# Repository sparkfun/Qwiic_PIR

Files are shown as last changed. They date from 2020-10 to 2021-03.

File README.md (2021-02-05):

SparkFun Qwiic PIR - 1&micro;A (EKMB1107112) & 170&micro;A (EKMC4607112K)
========================================

<table class="table table-hover table-striped table-bordered">
    <tr align="center">
      <td></td>
      <td></td>
    </tr>
    <tr align="center">
      <td><a href="https://www.sparkfun.com/products/17375">SparkFun Qwiic PIR - 1&micro;A (EKMB1107112)</a></td>
      <td><a href="https://www.sparkfun.com/products/17374">SparkFun Qwiic PIR - 170&micro;A (EKMC4607112K)</a></td>
    </tr>
</table>

The SparkFun Qwiic PIRs feature low-profile EKM-series PIR sensors from Panasonic for motion sensing projects using I<sup>2</sup>C. The two versions offer motion-sensing options for both battery powered (SparkFun Qwiic PIR - 1&micro;A (EKMB1107112)) and continuously powered (SparkFun Qwiic PIR - 170&micro;A (EKMC4607112K)) applications. The Qwiic PIR features an ATTiny84 to translate the PIR's digital output signal into I<sup>2</sup>C data so it can be integrated into an existing Qwiic or I<sup>2</sup>C bus.

Repository Contents
-------------------

* **/Documentation** - Data sheets, additional product information
* **/Firmware** - Qwiic PIR Firmware
* **/Hardware** - Eagle design files (.brd, .sch)
* **/Production** - Production panel files (.brd)

Documentation
--------------
* **[Qwiic PIR Arduino Library](https://github.com/sparkfun/SparkFun_Qwiic_PIR_Arduino_Library)** - Arduino library for the SparkFun Qwiic PIR.
* **[Qwiic PIR Python Library](https://github.com/sparkfun/Qwiic_PIR_Py)** - Python library for the SparkFun Qwiic PIR.
* **[Hookup Guide](https://learn.sparkfun.com/tutorials/qwiic-pir-hookup-guide)** - Basic hookup guide for the SparkFun Qwiic PIR.
* **[SparkFun Fritzing repo](https://github.com/sparkfun/Fritzing_Parts)** - Fritzing diagrams for SparkFun products.

Product Versions
----------------
* [SEN-17374](https://www.sparkfun.com/products/17374) - 170&micro;A version
* [SEN-17375](https://www.sparkfun.com/products/17375) - 1&micro;A version

Version History
---------------
* [v10](https://www.sparkfun.com/products/17374) - Initial release of SparkFun Qwiic PIR - 170&micro;A

License Information
-------------------

This product is _**open source**_! 

Please review the LICENSE.md file for license information. 

If you have any questions or concerns on licensing, please contact technical support on our [SparkFun forums](https://forum.sparkfun.com/viewforum.php?f=152).

Distributed as-is; no warranty is given.

- Your friends at SparkFun.

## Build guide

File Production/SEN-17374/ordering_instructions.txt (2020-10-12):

panel size, 195x143mm
PCB thickness, 1.6mm
number of layers, 2
soldermask color, Red
silkscreen color, White
oz copper, 1oz
finish, HASL lead free
stencils, top
pcs per panel, 35
min trace width, 0.1778mm / 0.0070in
min drill size, 0.3810mm / 0.0150in

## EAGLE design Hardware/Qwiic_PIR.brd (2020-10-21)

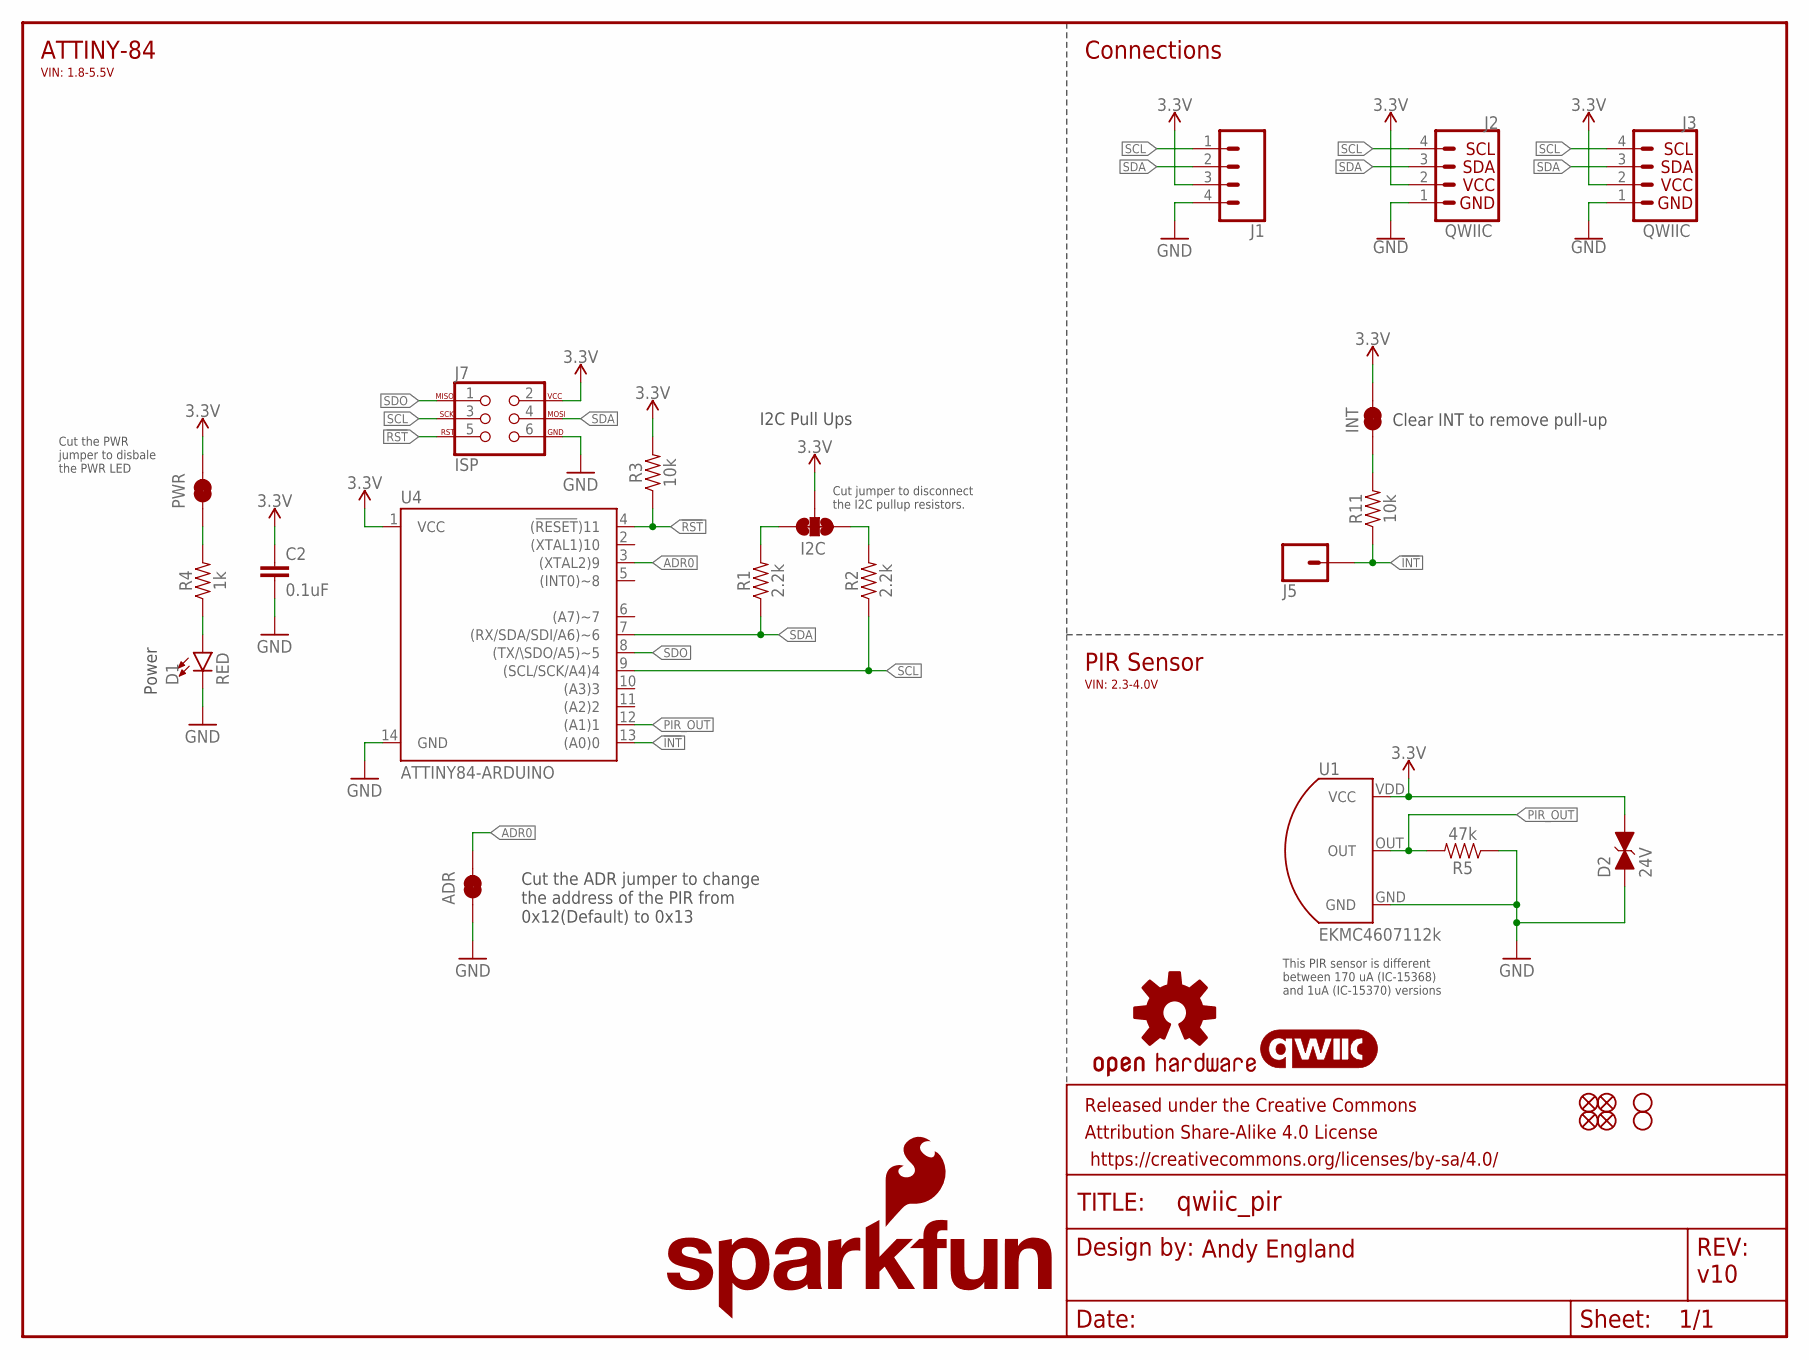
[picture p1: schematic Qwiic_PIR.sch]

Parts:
ADR: JUMPER-SMT_2_NC_TRACE_SILK; SMT-JUMPER_2_NC_TRACE_SILK
C2: 0.1uF; 0603
D1: RED; LED-0603
D2: 24V; 0603
FRAME1: FRAME-LETTER; CREATIVE_COMMONS
H1, H2: STAND-OFF
I2C: JUMPER-SMT_3_2-NC_TRACE_SILK; SMT-JUMPER_3_2-NC_TRACE_SILK
INT: JUMPER-SMT_2_NC_TRACE_SILK; SMT-JUMPER_2_NC_TRACE_SILK
J1: CONN_041X04_NO_SILK; 1X04_NO_SILK
J2, J3: QWIIC; JST04_1MM_RA
J5: CONN_01PTH_NO_SILK_YES_STOP; 1X01_NO_SILK
J7: ISP; 2X3_TEST_POINTS
JP2, JP6, JP8, JP9: FIDUCIALUFIDUCIAL; MICRO-FIDUCIAL
LOGO1: OSHW-LOGOMINI; OSHW-LOGO-MINI
LOGO2: QWIIC_LOGO_5MM; QWIIC_5MM
LOGO3: SFE_LOGO_NAME.1_INCH; SFE_LOGO_NAME_.1
LOGO4: SFE_LOGO_FLAME.1_INCH; SFE_LOGO_FLAME_.1
PWR: JUMPER-SMT_2_NC_TRACE_SILK; SMT-JUMPER_2_NC_TRACE_SILK
R1, R2: 2.2k; 0603
R3, R11: 10k; 0603
R4: 1k; 0603
R5: 47k; 0603
U1: EKMC4607112k; TO-3
U4: ATTINY84-ARDUINO; SO14

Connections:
3.3V: C2.1, D2.2 (C), I2C.2, INT.2, J1.3, J2.2, J3.2, J7.2, PWR.2, R3.2, U1.VDD (VCC), U4.1 (VCC)
!INT: J5.1, R11.1, U4.13 ((A0)0)
!RST: J7.5, R3.1, U4.4 ((!RESET!)11)
ADR0: ADR.2, U4.3 ((XTAL2)9)
GND: ADR.1, C2.2, D1.C, D2.1 (A), J1.4, J2.1, J3.1, J7.6, R5.1, U1.GND, U4.14 (GND)
INT_R: INT.1, R11.2
unnamed: D1.A, R4.1
PIR_OUT: R5.2, U1.OUT, U4.12 ((A1)1)
SCL: J1.1, J2.4, J3.4, J7.3, R2.1, U4.9 ((SCL/SCK/A4)4)
SCL_PU1: I2C.1, R2.2
SDA: J1.2, J2.3, J3.3, J7.4, R1.1, U4.7 ((RX/SDA/SDI/A6)~6)
SDA_PU1: I2C.3, R1.2
SDO: J7.1, U4.8 ((TX/\SDO/A5)~5)
STAT: PWR.1, R4.2

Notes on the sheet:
v10
Connections
Cut jumper to disconnect the I2C pullup resistors.
Cut the ADR jumper to change the address of the PIR from 0x12(Default) to 0x13
I2C Pull Ups
Power
Clear INT to remove pull-up
Andy England
ATTINY-84
PIR Sensor
VIN: 1.8-5.5V
Cut the PWR jumper to disbale the PWR LED
VIN: 2.3-4.0V
This PIR sensor is different between 170 uA (IC-15368) and 1uA (IC-15370) versions

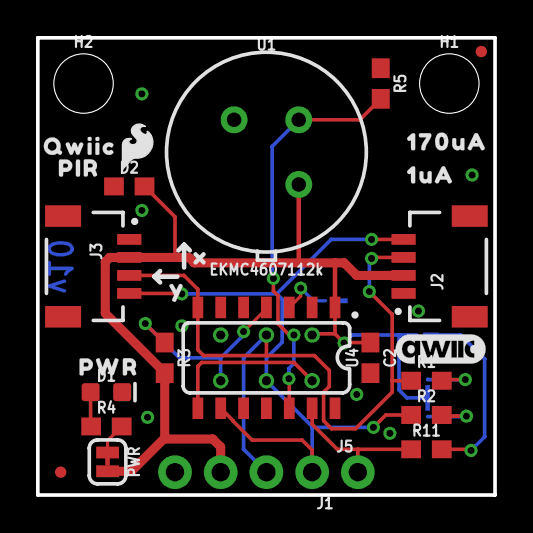
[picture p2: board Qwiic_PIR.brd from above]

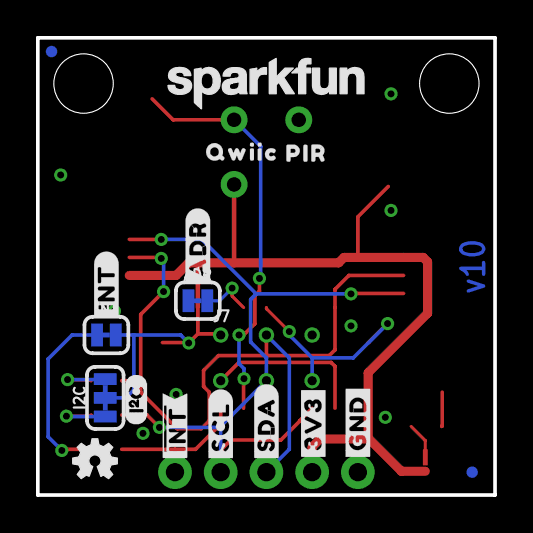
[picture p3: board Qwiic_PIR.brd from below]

Board: 2 copper layers, 25.4 x 25.4 mm, 48 parts (18 on the bottom side), 14 nets.

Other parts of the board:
U$1, U$13: PIR0
U$2: 170UA0
U$3: PWR0
U$4: #INT#0
U$5: #3V3#0
U$6: #SDA#0
U$7: #SCL#0
U$8: ##INT##0
U$9: 1UA0
U$10: I_SUPER2_C-()-03
U$11: #ADR#0
U$14: X0
U$16: Y0
U$17, U$18: QWIIC0
U$19: #GND#0

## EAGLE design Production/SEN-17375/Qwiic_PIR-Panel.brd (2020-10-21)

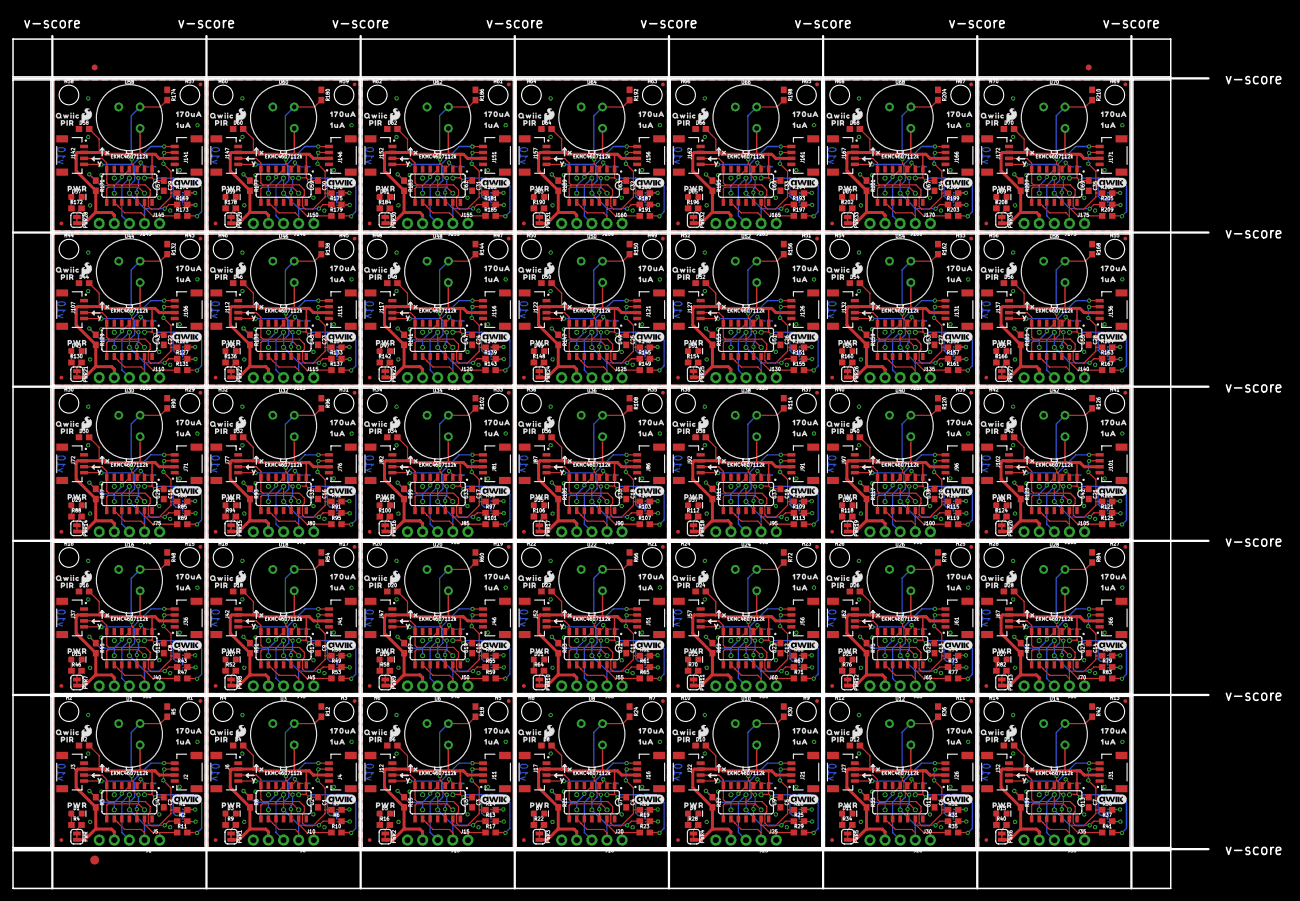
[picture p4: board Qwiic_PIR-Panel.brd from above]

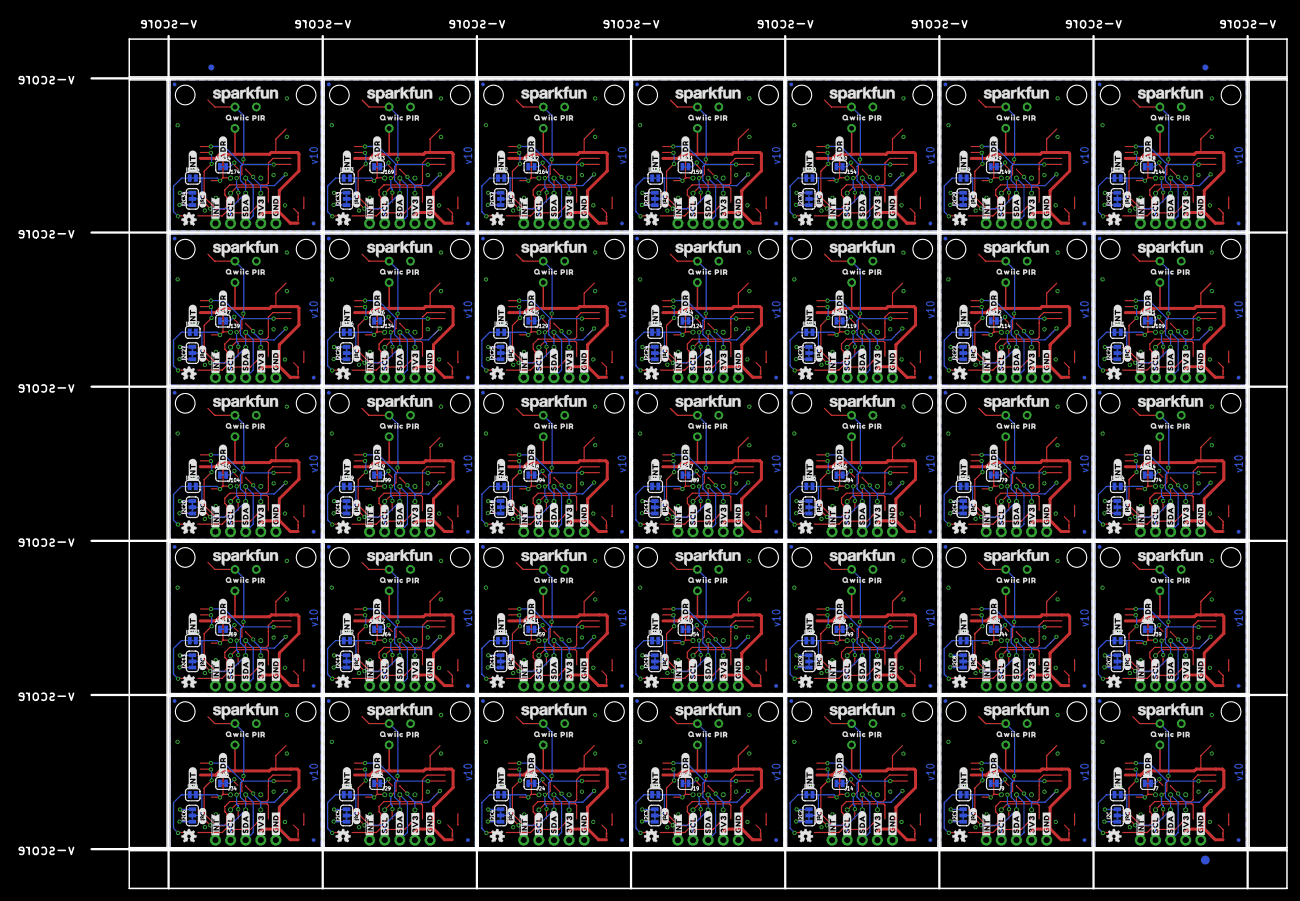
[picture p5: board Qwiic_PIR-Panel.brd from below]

Board: 2 copper layers, 200.9 x 143.3 mm, 1651 parts (633 on the bottom side), 490 nets.

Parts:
ADR, ADR1, ADR2, ADR3, ADR4, ADR5, ADR6, ADR7, ADR8, ADR9, ADR10, ADR11, ADR12, ADR13, ADR14, ADR15, ADR16, ADR17, ADR18, ADR19, ADR20, ADR21, ADR22, ADR23, ADR24, ADR25, ADR26, ADR27, ADR28, ADR29, ADR30, ADR31, ADR32, ADR33, ADR34: JUMPER-SMT_2_NC_TRACE_SILK; SMT-JUMPER_2_NC_TRACE_SILK
C1, C2, C3, C4, C5, C6, C7, C8, C9, C10, C11, C12, C13, C14, C15, C16, C17, C18, C19, C20, C21, C22, C23, C24, C25, C26, C27, C28, C29, C30, C31, C32, C33, C34, C35: 0.1uF; 0603
D1, D3, D5, D7, D9, D11, D13, D15, D17, D19, D21, D23, D25, D27, D29, D31, D33, D35, D37, D39, D41, D43, D45, D47, D49, D51, D53, D55, D57, D59, D61, D63, D65, D67, D69: RED; LED-0603
D2, D4, D6, D8, D10, D12, D14, D16, D18, D20, D22, D24, D26, D28, D30, D32, D34, D36, D38, D40, D42, D44, D46, D48, D50, D52, D54, D56, D58, D60, D62, D64, D66, D68, D70: 24V; 0603
E$1, E$2, E$3, E$4: FIDUCIAL-1X2
E$5, E$6: FIDUCIAL-1.5X3
H1, H2, H3, H4, H5, H6, H7, H8, H9, H10, H11, H12, H13, H14, H15, H16, H17, H18, H19, H20, H21, H22, H23, H24, H25, H26, H27, H28, H29, H30, H31, H32, H33, H34, H35, H36, H37, H38, H39, H40, H41, H42, H43, H44, H45, H46, H47, H48, H49, H50, H51, H52, H53, H54, H55, H56, H57, H58, H59, H60, H61, H62, H63, H64, H65, H66, H67, H68, H69, H70: STAND-OFF
I2C, I2C1, I2C2, I2C3, I2C4, I2C5, I2C6, I2C7, I2C8, I2C9, I2C10, I2C11, I2C12, I2C13, I2C14, I2C15, I2C16, I2C17, I2C18, I2C19, I2C20, I2C21, I2C22, I2C23, I2C24, I2C25, I2C26, I2C27, I2C28, I2C29, I2C30, I2C31, I2C32, I2C33, I2C34: JUMPER-SMT_3_2-NC_TRACE_SILK; SMT-JUMPER_3_2-NC_TRACE_SILK
INT, INT1, INT2, INT3, INT4, INT5, INT6, INT7, INT8, INT9, INT10, INT11, INT12, INT13, INT14, INT15, INT16, INT17, INT18, INT19, INT20, INT21, INT22, INT23, INT24, INT25, INT26, INT27, INT28, INT29, INT30, INT31, INT32, INT33, INT34: JUMPER-SMT_2_NC_TRACE_SILK; SMT-JUMPER_2_NC_TRACE_SILK
J1, J8, J13, J18, J23, J28, J33, J38, J43, J48, J53, J58, J63, J68, J73, J78, J83, J88, J93, J98, J103, J108, J113, J118, J123, J128, J133, J138, J143, J148, J153, J158, J163, J168, J173: 1X04_NO_SILK
J2, J3, J4, J6, J11, J12, J16, J17, J21, J22, J26, J27, J31, J32, J36, J37, J41, J42, J46, J47, J51, J52, J56, J57, J61, J62, J66, J67, J71, J72, J76, J77, J81, J82, J86, J87, J91, J92, J96, J97, J101, J102, J106, J107, J111, J112, J116, J117, J121, J122, J126, J127, J131, J132, J136, J137, J141, J142, J146, J147, J151, J152, J156, J157, J161, J162, J166, J167, J171, J172: QWIIC; JST04_1MM_RA
J5, J10, J15, J20, J25, J30, J35, J40, J45, J50, J55, J60, J65, J70, J75, J80, J85, J90, J95, J100, J105, J110, J115, J120, J125, J130, J135, J140, J145, J150, J155, J160, J165, J170, J175: 1X01_NO_SILK
J7, J9, J14, J19, J24, J29, J34, J39, J44, J49, J54, J59, J64, J69, J74, J79, J84, J89, J94, J99, J104, J109, J114, J119, J124, J129, J134, J139, J144, J149, J154, J159, J164, J169, J174: ISP; 2X3_TEST_POINTS
JP1, JP2, JP3, JP4, JP5, JP6, JP7, JP8, JP9, JP10, JP11, JP12, JP13, JP14, JP15, JP16, JP17, JP18, JP19, JP20, JP21, JP22, JP23, JP24, JP25, JP26, JP27, JP28, JP29, JP30, JP31, JP32, JP33, JP34, JP35, JP36, JP37, JP38, JP39, JP40, JP41, JP42, JP43, JP44, JP45, JP46, JP47, JP48, JP49, JP50, JP51, JP52, JP53, JP54, JP55, JP56, JP57, JP58, JP59, JP60, JP61, JP62, JP63, JP64, JP65, JP66, JP67, JP68, JP69, JP70, JP71, JP72, JP73, JP74, JP75, JP76, JP77, JP78, JP79, JP80, JP81, JP82, JP83, JP84, JP85, JP86, JP87, JP88, JP89, JP90, JP91, JP92, JP93, JP94, JP95, JP96, JP97, JP98, JP99, JP100, JP101, JP102, JP103, JP104, JP105, JP106, JP107, JP108, JP109, JP110, JP111, JP112, JP113, JP114, JP115, JP116, JP117, JP118, JP119, JP120, JP121, JP122, JP123, JP124, JP125, JP126, JP127, JP128, JP129, JP130, JP131, JP132, JP133, JP134, JP135, JP136, JP137, JP138, JP139, JP140: FIDUCIALUFIDUCIAL; MICRO-FIDUCIAL
LOGO1, LOGO5, LOGO9, LOGO13, LOGO17, LOGO21, LOGO25, LOGO29, LOGO33, LOGO37, LOGO41, LOGO45, LOGO49, LOGO53, LOGO57, LOGO61, LOGO65, LOGO69, LOGO73, LOGO77, LOGO81, LOGO85, LOGO89, LOGO93, LOGO97, LOGO101, LOGO105, LOGO109, LOGO113, LOGO117, LOGO121, LOGO125, LOGO129, LOGO133, LOGO137: OSHW-LOGOMINI; OSHW-LOGO-MINI
LOGO2, LOGO8, LOGO12, LOGO16, LOGO20, LOGO24, LOGO28, LOGO32, LOGO36, LOGO40, LOGO44, LOGO48, LOGO52, LOGO56, LOGO60, LOGO64, LOGO68, LOGO72, LOGO76, LOGO80, LOGO84, LOGO88, LOGO92, LOGO96, LOGO100, LOGO104, LOGO108, LOGO112, LOGO116, LOGO120, LOGO124, LOGO128, LOGO132, LOGO136, LOGO140: QWIIC_LOGO_5MM; QWIIC_5MM
LOGO3, LOGO6, LOGO10, LOGO14, LOGO18, LOGO22, LOGO26, LOGO30, LOGO34, LOGO38, LOGO42, LOGO46, LOGO50, LOGO54, LOGO58, LOGO62, LOGO66, LOGO70, LOGO74, LOGO78, LOGO82, LOGO86, LOGO90, LOGO94, LOGO98, LOGO102, LOGO106, LOGO110, LOGO114, LOGO118, LOGO122, LOGO126, LOGO130, LOGO134, LOGO138: SFE_LOGO_NAME.1_INCH; SFE_LOGO_NAME_.1
LOGO4, LOGO7, LOGO11, LOGO15, LOGO19, LOGO23, LOGO27, LOGO31, LOGO35, LOGO39, LOGO43, LOGO47, LOGO51, LOGO55, LOGO59, LOGO63, LOGO67, LOGO71, LOGO75, LOGO79, LOGO83, LOGO87, LOGO91, LOGO95, LOGO99, LOGO103, LOGO107, LOGO111, LOGO115, LOGO119, LOGO123, LOGO127, LOGO131, LOGO135, LOGO139: SFE_LOGO_FLAME.1_INCH; SFE_LOGO_FLAME_.1
PWR, PWR1, PWR2, PWR3, PWR4, PWR5, PWR6, PWR7, PWR8, PWR9, PWR10, PWR11, PWR12, PWR13, PWR14, PWR15, PWR16, PWR17, PWR18, PWR19, PWR20, PWR21, PWR22, PWR23, PWR24, PWR25, PWR26, PWR27, PWR28, PWR29, PWR30, PWR31, PWR32, PWR33, PWR34: JUMPER-SMT_2_NC_TRACE_SILK; SMT-JUMPER_2_NC_TRACE_SILK
R1, R2, R6, R7, R13, R14, R19, R20, R25, R26, R31, R32, R37, R38, R43, R44, R49, R50, R55, R56, R61, R62, R67, R68, R73, R74, R79, R80, R85, R86, R91, R92, R97, R98, R103, R104, R109, R110, R115, R116, R121, R122, R127, R128, R133, R134, R139, R140, R145, R146, R151, R152, R157, R158, R163, R164, R169, R170, R175, R176, R181, R182, R187, R188, R193, R194, R199, R200, R205, R206: 2.2k; 0603
R3, R8, R10, R11, R15, R17, R21, R23, R27, R29, R33, R35, R39, R41, R45, R47, R51, R53, R57, R59, R63, R65, R69, R71, R75, R77, R81, R83, R87, R89, R93, R95, R99, R101, R105, R107, R111, R113, R117, R119, R123, R125, R129, R131, R135, R137, R141, R143, R147, R149, R153, R155, R159, R161, R165, R167, R171, R173, R177, R179, R183, R185, R189, R191, R195, R197, R201, R203, R207, R209: 10k; 0603
R4, R9, R16, R22, R28, R34, R40, R46, R52, R58, R64, R70, R76, R82, R88, R94, R100, R106, R112, R118, R124, R130, R136, R142, R148, R154, R160, R166, R172, R178, R184, R190, R196, R202, R208: 1k; 0603
R5, R12, R18, R24, R30, R36, R42, R48, R54, R60, R66, R72, R78, R84, R90, R96, R102, R108, R114, R120, R126, R132, R138, R144, R150, R156, R162, R168, R174, R180, R186, R192, R198, R204, R210: 47k; 0603
U1, U3, U6, U8, U10, U12, U14, U16, U18, U20, U22, U24, U26, U28, U30, U32, U34, U36, U38, U40, U42, U44, U46, U48, U50, U52, U54, U56, U58, U60, U62, U64, U66, U68, U70: EKMC4607112k; TO-3
U2, U4, U5, U7, U9, U11, U13, U15, U17, U19, U21, U23, U25, U27, U29, U31, U33, U35, U37, U39, U41, U43, U45, U47, U49, U51, U53, U55, U57, U59, U61, U63, U65, U67, U69: ATTINY84-ARDUINO; SO14
U$1, U$13, U$15, U$23, U$36, U$40, U$53, U$57, U$70, U$74, U$87, U$91, U$104, U$108, U$121, U$125, U$138, U$142, U$155, U$159, U$172, U$176, U$189, U$193, U$206, U$210, U$223, U$227, U$240, U$244, U$257, U$261, U$274, U$278, U$291, U$295, U$308, U$312, U$325, U$329, U$342, U$346, U$359, U$363, U$376, U$380, U$393, U$397, U$410, U$414, U$427, U$431, U$444, U$448, U$461, U$465, U$478, U$482, U$495, U$499, U$512, U$516, U$529, U$533, U$546, U$550, U$563, U$567, U$580, U$584: PIR0
U$2, U$24, U$41, U$58, U$75, U$92, U$109, U$126, U$143, U$160, U$177, U$194, U$211, U$228, U$245, U$262, U$279, U$296, U$313, U$330, U$347, U$364, U$381, U$398, U$415, U$432, U$449, U$466, U$483, U$500, U$517, U$534, U$551, U$568, U$585: 170UA0
U$3, U$20, U$37, U$54, U$71, U$88, U$105, U$122, U$139, U$156, U$173, U$190, U$207, U$224, U$241, U$258, U$275, U$292, U$309, U$326, U$343, U$360, U$377, U$394, U$411, U$428, U$445, U$462, U$479, U$496, U$513, U$530, U$547, U$564, U$581: PWR0
U$4, U$21, U$38, U$55, U$72, U$89, U$106, U$123, U$140, U$157, U$174, U$191, U$208, U$225, U$242, U$259, U$276, U$293, U$310, U$327, U$344, U$361, U$378, U$395, U$412, U$429, U$446, U$463, U$480, U$497, U$514, U$531, U$548, U$565, U$582: #INT#0
U$5, U$31, U$48, U$65, U$82, U$99, U$116, U$133, U$150, U$167, U$184, U$201, U$218, U$235, U$252, U$269, U$286, U$303, U$320, U$337, U$354, U$371, U$388, U$405, U$422, U$439, U$456, U$473, U$490, U$507, U$524, U$541, U$558, U$575, U$592: #3V3#0
U$6, U$32, U$49, U$66, U$83, U$100, U$117, U$134, U$151, U$168, U$185, U$202, U$219, U$236, U$253, U$270, U$287, U$304, U$321, U$338, U$355, U$372, U$389, U$406, U$423, U$440, U$457, U$474, U$491, U$508, U$525, U$542, U$559, U$576, U$593: #SDA#0
U$7, U$33, U$50, U$67, U$84, U$101, U$118, U$135, U$152, U$169, U$186, U$203, U$220, U$237, U$254, U$271, U$288, U$305, U$322, U$339, U$356, U$373, U$390, U$407, U$424, U$441, U$458, U$475, U$492, U$509, U$526, U$543, U$560, U$577, U$594: #SCL#0
U$8, U$34, U$51, U$68, U$85, U$102, U$119, U$136, U$153, U$170, U$187, U$204, U$221, U$238, U$255, U$272, U$289, U$306, U$323, U$340, U$357, U$374, U$391, U$408, U$425, U$442, U$459, U$476, U$493, U$510, U$527, U$544, U$561, U$578, U$595: ##INT##0
U$9, U$25, U$42, U$59, U$76, U$93, U$110, U$127, U$144, U$161, U$178, U$195, U$212, U$229, U$246, U$263, U$280, U$297, U$314, U$331, U$348, U$365, U$382, U$399, U$416, U$433, U$450, U$467, U$484, U$501, U$518, U$535, U$552, U$569, U$586: 1UA0
U$10, U$12, U$35, U$52, U$69, U$86, U$103, U$120, U$137, U$154, U$171, U$188, U$205, U$222, U$239, U$256, U$273, U$290, U$307, U$324, U$341, U$358, U$375, U$392, U$409, U$426, U$443, U$460, U$477, U$494, U$511, U$528, U$545, U$562, U$579: I_SUPER2_C-()-03
U$11, U$22, U$39, U$56, U$73, U$90, U$107, U$124, U$141, U$158, U$175, U$192, U$209, U$226, U$243, U$260, U$277, U$294, U$311, U$328, U$345, U$362, U$379, U$396, U$413, U$430, U$447, U$464, U$481, U$498, U$515, U$532, U$549, U$566, U$583: #ADR#0
U$14, U$26, U$43, U$60, U$77, U$94, U$111, U$128, U$145, U$162, U$179, U$196, U$213, U$230, U$247, U$264, U$281, U$298, U$315, U$332, U$349, U$366, U$383, U$400, U$417, U$434, U$451, U$468, U$485, U$502, U$519, U$536, U$553, U$570, U$587: X0
U$16, U$27, U$44, U$61, U$78, U$95, U$112, U$129, U$146, U$163, U$180, U$197, U$214, U$231, U$248, U$265, U$282, U$299, U$316, U$333, U$350, U$367, U$384, U$401, U$418, U$435, U$452, U$469, U$486, U$503, U$520, U$537, U$554, U$571, U$588: Y0
U$17, U$18, U$28, U$29, U$45, U$46, U$62, U$63, U$79, U$80, U$96, U$97, U$113, U$114, U$130, U$131, U$147, U$148, U$164, U$165, U$181, U$182, U$198, U$199, U$215, U$216, U$232, U$233, U$249, U$250, U$266, U$267, U$283, U$284, U$300, U$301, U$317, U$318, U$334, U$335, U$351, U$352, U$368, U$369, U$385, U$386, U$402, U$403, U$419, U$420, U$436, U$437, U$453, U$454, U$470, U$471, U$487, U$488, U$504, U$505, U$521, U$522, U$538, U$539, U$555, U$556, U$572, U$573, U$589, U$590: QWIIC0
U$19, U$30, U$47, U$64, U$81, U$98, U$115, U$132, U$149, U$166, U$183, U$200, U$217, U$234, U$251, U$268, U$285, U$302, U$319, U$336, U$353, U$370, U$387, U$404, U$421, U$438, U$455, U$472, U$489, U$506, U$523, U$540, U$557, U$574, U$591: #GND#0

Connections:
3.3V: C2.1, D2.2, I2C.2, INT.2, J1.3, J2.2, J3.2, J7.2, PWR.2, R3.2, U1.VDD, U4.1
3.3V1: C1.1, D4.2, I2C1.2, INT1.2, J4.2, J6.2, J8.3, J9.2, PWR1.2, R8.2, U2.1, U3.VDD
3.3V2: C3.1, D6.2, I2C2.2, INT2.2, J11.2, J12.2, J13.3, J14.2, PWR2.2, R15.2, U5.1, U6.VDD
3.3V3: C4.1, D8.2, I2C3.2, INT3.2, J16.2, J17.2, J18.3, J19.2, PWR3.2, R21.2, U7.1, U8.VDD
3.3V4: C5.1, D10.2, I2C4.2, INT4.2, J21.2, J22.2, J23.3, J24.2, PWR4.2, R27.2, U9.1, U10.VDD
3.3V5: C6.1, D12.2, I2C5.2, INT5.2, J26.2, J27.2, J28.3, J29.2, PWR5.2, R33.2, U11.1, U12.VDD
3.3V6: C7.1, D14.2, I2C6.2, INT6.2, J31.2, J32.2, J33.3, J34.2, PWR6.2, R39.2, U13.1, U14.VDD
3.3V7: C8.1, D16.2, I2C7.2, INT7.2, J36.2, J37.2, J38.3, J39.2, PWR7.2, R45.2, U15.1, U16.VDD
3.3V8: C9.1, D18.2, I2C8.2, INT8.2, J41.2, J42.2, J43.3, J44.2, PWR8.2, R51.2, U17.1, U18.VDD
3.3V9: C10.1, D20.2, I2C9.2, INT9.2, J46.2, J47.2, J48.3, J49.2, PWR9.2, R57.2, U19.1, U20.VDD
3.3V10: C11.1, D22.2, I2C10.2, INT10.2, J51.2, J52.2, J53.3, J54.2, PWR10.2, R63.2, U21.1, U22.VDD
3.3V11: C12.1, D24.2, I2C11.2, INT11.2, J56.2, J57.2, J58.3, J59.2, PWR11.2, R69.2, U23.1, U24.VDD
3.3V12: C13.1, D26.2, I2C12.2, INT12.2, J61.2, J62.2, J63.3, J64.2, PWR12.2, R75.2, U25.1, U26.VDD
3.3V13: C14.1, D28.2, I2C13.2, INT13.2, J66.2, J67.2, J68.3, J69.2, PWR13.2, R81.2, U27.1, U28.VDD
3.3V14: C15.1, D30.2, I2C14.2, INT14.2, J71.2, J72.2, J73.3, J74.2, PWR14.2, R87.2, U29.1, U30.VDD
3.3V15: C16.1, D32.2, I2C15.2, INT15.2, J76.2, J77.2, J78.3, J79.2, PWR15.2, R93.2, U31.1, U32.VDD
3.3V16: C17.1, D34.2, I2C16.2, INT16.2, J81.2, J82.2, J83.3, J84.2, PWR16.2, R99.2, U33.1, U34.VDD
3.3V17: C18.1, D36.2, I2C17.2, INT17.2, J86.2, J87.2, J88.3, J89.2, PWR17.2, R105.2, U35.1, U36.VDD
3.3V18: C19.1, D38.2, I2C18.2, INT18.2, J91.2, J92.2, J93.3, J94.2, PWR18.2, R111.2, U37.1, U38.VDD
3.3V19: C20.1, D40.2, I2C19.2, INT19.2, J96.2, J97.2, J98.3, J99.2, PWR19.2, R117.2, U39.1, U40.VDD
3.3V20: C21.1, D42.2, I2C20.2, INT20.2, J101.2, J102.2, J103.3, J104.2, PWR20.2, R123.2, U41.1, U42.VDD
3.3V21: C22.1, D44.2, I2C21.2, INT21.2, J106.2, J107.2, J108.3, J109.2, PWR21.2, R129.2, U43.1, U44.VDD
3.3V22: C23.1, D46.2, I2C22.2, INT22.2, J111.2, J112.2, J113.3, J114.2, PWR22.2, R135.2, U45.1, U46.VDD
3.3V23: C24.1, D48.2, I2C23.2, INT23.2, J116.2, J117.2, J118.3, J119.2, PWR23.2, R141.2, U47.1, U48.VDD
3.3V24: C25.1, D50.2, I2C24.2, INT24.2, J121.2, J122.2, J123.3, J124.2, PWR24.2, R147.2, U49.1, U50.VDD
3.3V25: C26.1, D52.2, I2C25.2, INT25.2, J126.2, J127.2, J128.3, J129.2, PWR25.2, R153.2, U51.1, U52.VDD
3.3V26: C27.1, D54.2, I2C26.2, INT26.2, J131.2, J132.2, J133.3, J134.2, PWR26.2, R159.2, U53.1, U54.VDD
3.3V27: C28.1, D56.2, I2C27.2, INT27.2, J136.2, J137.2, J138.3, J139.2, PWR27.2, R165.2, U55.1, U56.VDD
3.3V28: C29.1, D58.2, I2C28.2, INT28.2, J141.2, J142.2, J143.3, J144.2, PWR28.2, R171.2, U57.1, U58.VDD
3.3V29: C30.1, D60.2, I2C29.2, INT29.2, J146.2, J147.2, J148.3, J149.2, PWR29.2, R177.2, U59.1, U60.VDD
3.3V30: C31.1, D62.2, I2C30.2, INT30.2, J151.2, J152.2, J153.3, J154.2, PWR30.2, R183.2, U61.1, U62.VDD
3.3V31: C32.1, D64.2, I2C31.2, INT31.2, J156.2, J157.2, J158.3, J159.2, PWR31.2, R189.2, U63.1, U64.VDD
3.3V32: C33.1, D66.2, I2C32.2, INT32.2, J161.2, J162.2, J163.3, J164.2, PWR32.2, R195.2, U65.1, U66.VDD
3.3V33: C34.1, D68.2, I2C33.2, INT33.2, J166.2, J167.2, J168.3, J169.2, PWR33.2, R201.2, U67.1, U68.VDD
3.3V34: C35.1, D70.2, I2C34.2, INT34.2, J171.2, J172.2, J173.3, J174.2, PWR34.2, R207.2, U69.1, U70.VDD
!INT: J5.1, R11.1, U4.13
!INT1: J10.1, R10.1, U2.13
!INT2: J15.1, R17.1, U5.13
!INT3: J20.1, R23.1, U7.13
!INT4: J25.1, R29.1, U9.13
!INT5: J30.1, R35.1, U11.13
!INT6: J35.1, R41.1, U13.13
!INT7: J40.1, R47.1, U15.13
!INT8: J45.1, R53.1, U17.13
!INT9: J50.1, R59.1, U19.13
!INT10: J55.1, R65.1, U21.13
!INT11: J60.1, R71.1, U23.13
!INT12: J65.1, R77.1, U25.13
!INT13: J70.1, R83.1, U27.13
!INT14: J75.1, R89.1, U29.13
!INT15: J80.1, R95.1, U31.13
!INT16: J85.1, R101.1, U33.13
!INT17: J90.1, R107.1, U35.13
!INT18: J95.1, R113.1, U37.13
!INT19: J100.1, R119.1, U39.13
!INT20: J105.1, R125.1, U41.13
!INT21: J110.1, R131.1, U43.13
!INT22: J115.1, R137.1, U45.13
!INT23: J120.1, R143.1, U47.13
!INT24: J125.1, R149.1, U49.13
!INT25: J130.1, R155.1, U51.13
!INT26: J135.1, R161.1, U53.13
!INT27: J140.1, R167.1, U55.13
!INT28: J145.1, R173.1, U57.13
!INT29: J150.1, R179.1, U59.13
!INT30: J155.1, R185.1, U61.13
!INT31: J160.1, R191.1, U63.13
!INT32: J165.1, R197.1, U65.13
!INT33: J170.1, R203.1, U67.13
!INT34: J175.1, R209.1, U69.13
!RST: J7.5, R3.1, U4.4
!RST1: J9.5, R8.1, U2.4
!RST2: J14.5, R15.1, U5.4
!RST3: J19.5, R21.1, U7.4
!RST4: J24.5, R27.1, U9.4
!RST5: J29.5, R33.1, U11.4
!RST6: J34.5, R39.1, U13.4
!RST7: J39.5, R45.1, U15.4
!RST8: J44.5, R51.1, U17.4
!RST9: J49.5, R57.1, U19.4
!RST10: J54.5, R63.1, U21.4
!RST11: J59.5, R69.1, U23.4
!RST12: J64.5, R75.1, U25.4
!RST13: J69.5, R81.1, U27.4
!RST14: J74.5, R87.1, U29.4
!RST15: J79.5, R93.1, U31.4
!RST16: J84.5, R99.1, U33.4
!RST17: J89.5, R105.1, U35.4
!RST18: J94.5, R111.1, U37.4
!RST19: J99.5, R117.1, U39.4
!RST20: J104.5, R123.1, U41.4
!RST21: J109.5, R129.1, U43.4
!RST22: J114.5, R135.1, U45.4
!RST23: J119.5, R141.1, U47.4
!RST24: J124.5, R147.1, U49.4
!RST25: J129.5, R153.1, U51.4
!RST26: J134.5, R159.1, U53.4
!RST27: J139.5, R165.1, U55.4
!RST28: J144.5, R171.1, U57.4
!RST29: J149.5, R177.1, U59.4
!RST30: J154.5, R183.1, U61.4
!RST31: J159.5, R189.1, U63.4
!RST32: J164.5, R195.1, U65.4
!RST33: J169.5, R201.1, U67.4
!RST34: J174.5, R207.1, U69.4
ADR0: ADR.2, U4.3
ADR1: ADR1.2, U2.3
ADR2: ADR2.2, U5.3
ADR3: ADR3.2, U7.3
ADR4: ADR4.2, U9.3
ADR5: ADR5.2, U11.3
ADR6: ADR6.2, U13.3
ADR7: ADR7.2, U15.3
ADR8: ADR8.2, U17.3
ADR9: ADR9.2, U19.3
ADR10: ADR10.2, U21.3
ADR11: ADR11.2, U23.3
ADR12: ADR12.2, U25.3
ADR13: ADR13.2, U27.3
ADR14: ADR14.2, U29.3
ADR15: ADR15.2, U31.3
ADR16: ADR16.2, U33.3
ADR17: ADR17.2, U35.3
ADR18: ADR18.2, U37.3
ADR19: ADR19.2, U39.3
ADR20: ADR20.2, U41.3
ADR21: ADR21.2, U43.3
ADR22: ADR22.2, U45.3
ADR23: ADR23.2, U47.3
ADR24: ADR24.2, U49.3
ADR25: ADR25.2, U51.3
ADR26: ADR26.2, U53.3
ADR27: ADR27.2, U55.3
ADR28: ADR28.2, U57.3
ADR29: ADR29.2, U59.3
ADR30: ADR30.2, U61.3
ADR31: ADR31.2, U63.3
ADR32: ADR32.2, U65.3
ADR33: ADR33.2, U67.3
ADR34: ADR34.2, U69.3
GND: ADR.1, C2.2, D1.C, D2.1, J1.4, J2.1, J3.1, J7.6, R5.1, U1.GND, U4.14
GND1: ADR1.1, C1.2, D3.C, D4.1, J4.1, J6.1, J8.4, J9.6, R12.1, U2.14, U3.GND
GND2: ADR2.1, C3.2, D5.C, D6.1, J11.1, J12.1, J13.4, J14.6, R18.1, U5.14, U6.GND
GND3: ADR3.1, C4.2, D7.C, D8.1, J16.1, J17.1, J18.4, J19.6, R24.1, U7.14, U8.GND
GND4: ADR4.1, C5.2, D9.C, D10.1, J21.1, J22.1, J23.4, J24.6, R30.1, U9.14, U10.GND
GND5: ADR5.1, C6.2, D11.C, D12.1, J26.1, J27.1, J28.4, J29.6, R36.1, U11.14, U12.GND
GND6: ADR6.1, C7.2, D13.C, D14.1, J31.1, J32.1, J33.4, J34.6, R42.1, U13.14, U14.GND
GND7: ADR7.1, C8.2, D15.C, D16.1, J36.1, J37.1, J38.4, J39.6, R48.1, U15.14, U16.GND
GND8: ADR8.1, C9.2, D17.C, D18.1, J41.1, J42.1, J43.4, J44.6, R54.1, U17.14, U18.GND
GND9: ADR9.1, C10.2, D19.C, D20.1, J46.1, J47.1, J48.4, J49.6, R60.1, U19.14, U20.GND
GND10: ADR10.1, C11.2, D21.C, D22.1, J51.1, J52.1, J53.4, J54.6, R66.1, U21.14, U22.GND
GND11: ADR11.1, C12.2, D23.C, D24.1, J56.1, J57.1, J58.4, J59.6, R72.1, U23.14, U24.GND
GND12: ADR12.1, C13.2, D25.C, D26.1, J61.1, J62.1, J63.4, J64.6, R78.1, U25.14, U26.GND
GND13: ADR13.1, C14.2, D27.C, D28.1, J66.1, J67.1, J68.4, J69.6, R84.1, U27.14, U28.GND
GND14: ADR14.1, C15.2, D29.C, D30.1, J71.1, J72.1, J73.4, J74.6, R90.1, U29.14, U30.GND
GND15: ADR15.1, C16.2, D31.C, D32.1, J76.1, J77.1, J78.4, J79.6, R96.1, U31.14, U32.GND
GND16: ADR16.1, C17.2, D33.C, D34.1, J81.1, J82.1, J83.4, J84.6, R102.1, U33.14, U34.GND
GND17: ADR17.1, C18.2, D35.C, D36.1, J86.1, J87.1, J88.4, J89.6, R108.1, U35.14, U36.GND
GND18: ADR18.1, C19.2, D37.C, D38.1, J91.1, J92.1, J93.4, J94.6, R114.1, U37.14, U38.GND
GND19: ADR19.1, C20.2, D39.C, D40.1, J96.1, J97.1, J98.4, J99.6, R120.1, U39.14, U40.GND
GND20: ADR20.1, C21.2, D41.C, D42.1, J101.1, J102.1, J103.4, J104.6, R126.1, U41.14, U42.GND
GND21: ADR21.1, C22.2, D43.C, D44.1, J106.1, J107.1, J108.4, J109.6, R132.1, U43.14, U44.GND
GND22: ADR22.1, C23.2, D45.C, D46.1, J111.1, J112.1, J113.4, J114.6, R138.1, U45.14, U46.GND
GND23: ADR23.1, C24.2, D47.C, D48.1, J116.1, J117.1, J118.4, J119.6, R144.1, U47.14, U48.GND
GND24: ADR24.1, C25.2, D49.C, D50.1, J121.1, J122.1, J123.4, J124.6, R150.1, U49.14, U50.GND
GND25: ADR25.1, C26.2, D51.C, D52.1, J126.1, J127.1, J128.4, J129.6, R156.1, U51.14, U52.GND
GND26: ADR26.1, C27.2, D53.C, D54.1, J131.1, J132.1, J133.4, J134.6, R162.1, U53.14, U54.GND
GND27: ADR27.1, C28.2, D55.C, D56.1, J136.1, J137.1, J138.4, J139.6, R168.1, U55.14, U56.GND
GND28: ADR28.1, C29.2, D57.C, D58.1, J141.1, J142.1, J143.4, J144.6, R174.1, U57.14, U58.GND
GND29: ADR29.1, C30.2, D59.C, D60.1, J146.1, J147.1, J148.4, J149.6, R180.1, U59.14, U60.GND
GND30: ADR30.1, C31.2, D61.C, D62.1, J151.1, J152.1, J153.4, J154.6, R186.1, U61.14, U62.GND
GND31: ADR31.1, C32.2, D63.C, D64.1, J156.1, J157.1, J158.4, J159.6, R192.1, U63.14, U64.GND
GND32: ADR32.1, C33.2, D65.C, D66.1, J161.1, J162.1, J163.4, J164.6, R198.1, U65.14, U66.GND
GND33: ADR33.1, C34.2, D67.C, D68.1, J166.1, J167.1, J168.4, J169.6, R204.1, U67.14, U68.GND
GND34: ADR34.1, C35.2, D69.C, D70.1, J171.1, J172.1, J173.4, J174.6, R210.1, U69.14, U70.GND
INT_R: INT.1, R11.2
INT_R1: INT1.1, R10.2
INT_R2: INT2.1, R17.2
INT_R3: INT3.1, R23.2
INT_R4: INT4.1, R29.2
INT_R5: INT5.1, R35.2
INT_R6: INT6.1, R41.2
INT_R7: INT7.1, R47.2
INT_R8: INT8.1, R53.2
INT_R9: INT9.1, R59.2
INT_R10: INT10.1, R65.2
INT_R11: INT11.1, R71.2
INT_R12: INT12.1, R77.2
INT_R13: INT13.1, R83.2
INT_R14: INT14.1, R89.2
INT_R15: INT15.1, R95.2
INT_R16: INT16.1, R101.2
INT_R17: INT17.1, R107.2
INT_R18: INT18.1, R113.2
INT_R19: INT19.1, R119.2
INT_R20: INT20.1, R125.2
INT_R21: INT21.1, R131.2
INT_R22: INT22.1, R137.2
INT_R23: INT23.1, R143.2
INT_R24: INT24.1, R149.2
INT_R25: INT25.1, R155.2
INT_R26: INT26.1, R161.2
INT_R27: INT27.1, R167.2
INT_R28: INT28.1, R173.2
INT_R29: INT29.1, R179.2
INT_R30: INT30.1, R185.2
INT_R31: INT31.1, R191.2
INT_R32: INT32.1, R197.2
INT_R33: INT33.1, R203.2
INT_R34: INT34.1, R209.2
unnamed: D3.A, R9.1
unnamed: D5.A, R16.1
unnamed: D1.A, R4.1
unnamed: D7.A, R22.1
unnamed: D9.A, R28.1
unnamed: D11.A, R34.1
unnamed: D13.A, R40.1
unnamed: D15.A, R46.1
unnamed: D17.A, R52.1
unnamed: D19.A, R58.1
unnamed: D21.A, R64.1
unnamed: D23.A, R70.1
unnamed: D25.A, R76.1
unnamed: D27.A, R82.1
unnamed: D29.A, R88.1
unnamed: D31.A, R94.1
unnamed: D33.A, R100.1
unnamed: D35.A, R106.1
unnamed: D37.A, R112.1
unnamed: D39.A, R118.1
unnamed: D41.A, R124.1
unnamed: D43.A, R130.1
unnamed: D45.A, R136.1
unnamed: D47.A, R142.1
unnamed: D49.A, R148.1
unnamed: D51.A, R154.1
unnamed: D53.A, R160.1
unnamed: D55.A, R166.1
unnamed: D57.A, R172.1
unnamed: D59.A, R178.1
unnamed: D61.A, R184.1
unnamed: D63.A, R190.1
unnamed: D65.A, R196.1
unnamed: D67.A, R202.1
unnamed: D69.A, R208.1
PIR_OUT: R5.2, U1.OUT, U4.12
PIR_OUT1: R12.2, U2.12, U3.OUT
PIR_OUT2: R18.2, U5.12, U6.OUT
PIR_OUT3: R24.2, U7.12, U8.OUT
PIR_OUT4: R30.2, U9.12, U10.OUT
PIR_OUT5: R36.2, U11.12, U12.OUT
PIR_OUT6: R42.2, U13.12, U14.OUT
PIR_OUT7: R48.2, U15.12, U16.OUT
PIR_OUT8: R54.2, U17.12, U18.OUT
PIR_OUT9: R60.2, U19.12, U20.OUT
PIR_OUT10: R66.2, U21.12, U22.OUT
PIR_OUT11: R72.2, U23.12, U24.OUT
PIR_OUT12: R78.2, U25.12, U26.OUT
PIR_OUT13: R84.2, U27.12, U28.OUT
PIR_OUT14: R90.2, U29.12, U30.OUT
PIR_OUT15: R96.2, U31.12, U32.OUT
PIR_OUT16: R102.2, U33.12, U34.OUT
PIR_OUT17: R108.2, U35.12, U36.OUT
PIR_OUT18: R114.2, U37.12, U38.OUT
PIR_OUT19: R120.2, U39.12, U40.OUT
PIR_OUT20: R126.2, U41.12, U42.OUT
PIR_OUT21: R132.2, U43.12, U44.OUT
PIR_OUT22: R138.2, U45.12, U46.OUT
PIR_OUT23: R144.2, U47.12, U48.OUT
PIR_OUT24: R150.2, U49.12, U50.OUT
PIR_OUT25: R156.2, U51.12, U52.OUT
PIR_OUT26: R162.2, U53.12, U54.OUT
PIR_OUT27: R168.2, U55.12, U56.OUT
PIR_OUT28: R174.2, U57.12, U58.OUT
PIR_OUT29: R180.2, U59.12, U60.OUT
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

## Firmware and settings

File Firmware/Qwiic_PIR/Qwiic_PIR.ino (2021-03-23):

/*
  An I2C based PIR
  By: Andy England and Priyanka Makin
  SparkFun Electronics
  Date: February 10, 2021
  License: This code is public domain but you buy me a beer if you use this and
  we meet someday (Beerware license).

  Qwiic PIR is an I2C based pir that records any PIR events to a queue

  Qwiic PIR maintains a queue of events. To remove events from the queue write
  the appropriate register (timeSinceLastPIREvent)
  to zero. The register will then be filled with the next available event time.

  There is also an accompanying Arduino Library located here:
  https://github.com/sparkfun/SparkFun_Qwiic_PIR_Arduino_Library

  Feel like supporting our work? Buy a board from SparkFun!
  https://www.sparkfun.com/products/14641

  To install support for ATtiny84 in Arduino IDE: https://github.com/SpenceKonde/ATTinyCore/blob/master/Installation.md
  This core is installed from the Board Manager menu
  This core has built in support for I2C S/M and serial
  If you have Dave Mellis' ATtiny installed you may need to remove it from \Users\xx\AppData\Local\Arduino15\Packages

  To support 400kHz I2C communication reliably ATtiny84 needs to run at 8MHz. This requires user to
  click on 'Burn Bootloader' before code is loaded.

  Library Inclusion:
  Wire.h        Used for interfacing with the I2C hardware for responding to I2C events.
  EEPROM.h      Used for interfacing with the onboard EEPROM for storing and retrieving settings.
  nvm.h         Used for defining the storage locations in non-volatile memory (EEPROM) to store and retrieve settings from.
  queue.h       Used for defining a FIFO-queue that contains the timestamps associated with PIR events
  registers.h   Used for defining a memoryMap object that serves as the register map for the device.

  PinChangeInterrupt.h    Nico Hood's library for triggering an interrupt on a pin state change (either low->high or high->low)
  avr/sleep.h             Needed for sleep_mode which saves power on the ATTiny
  avr/power.hardware      Needed for powering down peripherals such as the ADC/TWI and Timers on the ATTiny
*/

#include <Wire.h>
#include <EEPROM.h>
#include "nvm.h"
#include "queue.h"
#include "registers.h"

#include "PinChangeInterrupt.h" //Nico Hood's library: https://github.com/NicoHood/PinChangeInterrupt/
//Used for pin change interrupts on ATtinys
//Note: To make this code work with Nico's library you have to comment out https://github.com/NicoHood/PinChangeInterrupt/blob/master/src/PinChangeInterruptSettings.h#L228

#include <avr/sleep.h> //Needed for sleep_mode
#include <avr/power.h> //Needed for powering down perihperals such as the ADC/TWI and Timers

#define DEVICE_ID 0x72
#define FIRMWARE_MAJOR 0x01 //Firmware Version. Helpful for tech support.
#define FIRMWARE_MINOR 0x01

#define DEFAULT_I2C_ADDRESS 0x12

#define SOFTWARE_ADDRESS true
#define HARDWARE_ADDRESS false

uint8_t oldAddress;

//Hardware connections
#if defined(__AVR_ATmega328P__)
//For developement on an Uno
const uint8_t addressPin = 3;
const uint8_t ledPin = 9; //PWM
const uint8_t statusLedPin = 8;
const uint8_t pirPin = 2;
const uint8_t interruptPin = 7; //pin is active-low, high-impedance when not triggered, goes low-impedance to ground when triggered

#elif defined(__AVR_ATtiny84__)
const uint8_t addressPin = 9;
const uint8_t ledPin = 7; //PWM
const uint8_t statusLedPin = 3;
const uint8_t pirPin = 1;
const uint8_t interruptPin = 0; //pin is active-low, high-impedance when not triggered, goes low-impedance to ground when triggered
#endif

//Global variables
//-=-=-=-=-=-=-=-=-=-=-=-=-=-=-=-=-=-=-=-=-=-=-=-=-=-=-=-=-=-=-=-=-=-=-=-=-=-=-=-=-=-=-=-=-=-
//These are the defaults for all settings

//Variables used in the I2C interrupt.ino file so we use volatile
volatile memoryMap registerMap {
  DEVICE_ID,           //id
  FIRMWARE_MINOR,      //firmwareMinor
  FIRMWARE_MAJOR,      //firmwareMajor
  {0, 0, 0, 0},           //eventStatus {rawReading, eventAvailable, objectRemoved, objectDetected}
  {1},              //interruptConfig {interruptEnable}
  0x02EE,              //eventDebounceTime, default: 750ms
  {0, 1, 0},           //eventQueueStatus {popRequest, isEmpty, isFull}
  0x00000000,          //eventQueueFront
  0x00000000,          //eventQueueBack
  {0, 1, 0},           //eventQueueStatus {popRequest, isEmpty, isFull}
  0x00000000,          //eventQueueFront
  0x00000000,          //eventQueueBack
  DEFAULT_I2C_ADDRESS, //i2cAddress
};

//This defines which of the registers are read-only (0) vs read-write (1)
memoryMap protectionMap = {
  0x00,       //id
  0x00,       //firmwareMinor
  0x00,       //firmwareMajor
  {0, 1, 1, 1},  //eventStatus {rawReading, eventAvailble, objectRemoved, objectDetected}
  {1},        //interruptConfig {interruptEnable}
  0xFFFF,     //eventDebounceTime
  {1, 0, 0},  //detectQueueStatus {popRequest, isEmpty, isFull}
  0x00000000, //detectQueueFront
  0x00000000, //detectQueueBack
  {1, 0, 0},  //removeQueueStatus {popRequest, isEmpty, isFull}
  0x00000000, //removeQueueFront
  0x00000000, //removeQueueBack
  0xFF,       //i2cAddress
};

//Cast 32bit address of the object registerMap with uint8_t so we can increment the pointer
uint8_t *registerPointer = (uint8_t *)&registerMap;
uint8_t *protectionPointer = (uint8_t *)&protectionMap;

volatile uint8_t registerNumber; //Gets set when user writes an address. We then serve the spot the user requested.

volatile boolean updateFlag = true; //Goes true when we receive new bytes from user. Causes LEDs and things to update in main loop.

volatile Queue detectEvents; //Init FIFO buffer for storing timestamps associated with PIR detect events
volatile Queue removedEvents; //Init FIFO buffer for storing timestamps associated with PIR remove events

volatile unsigned long lastEventTime = 0; //Used for debouncing

//-=-=-=-=-=-=-=-=-=-=-=-=-=-=-=-=-=-=-=-=-=-=-=-=-=-=-=-=-=-=-=-=-=-=-=-=-=-=-=-=-=-=-=-=-=-

void setup(void)
{
  pinMode(addressPin, INPUT_PULLUP); //Internally pull up address pins

  pinMode(pirPin, INPUT);
#if defined(__AVR_ATmega328P__)
  pinMode(interruptPin, INPUT_PULLUP);     //High-impedance input until we have an int and then we output low. Pulled high with 10k with cuttable jumper.
#else
  pinMode(interruptPin, INPUT);     //High-impedance input until we have an int and then we output low. Pulled high with 10k with cuttable jumper.
#endif

  //Disable ADC
  ADCSRA = 0;

  //Disable Brown-Out Detect
  MCUCR = bit(BODS) | bit(BODSE);
  MCUCR = bit(BODS);

  //Power down various bits of hardware to lower power usage
  //set_sleep_mode(SLEEP_MODE_PWR_DOWN); //May turn off millis
  set_sleep_mode(SLEEP_MODE_IDLE);
  sleep_enable();

#if defined(__AVR_ATmega328P__)

  for (int x = 0; x < 100; x++) {
    EEPROM.put(x, 0xFF);
  }

  Serial.begin(115200);
  Serial.println("Qwiic PIR");
  Serial.print("Address: 0x");
  Serial.println(registerMap.i2cAddress, HEX);
  Serial.print("Device ID: 0x");
  Serial.println(registerMap.id, HEX);

#endif

  readSystemSettings(&registerMap); //Load all system settings from EEPROM

#if defined(__AVR_ATmega328P__)
  //Debug values
#endif

  setupInterrupts();               //Enable pin change interrupts for I2C, switch, etc
  startI2C(&registerMap);          //Determine the I2C address we should be using and begin listening on I2C bus
  oldAddress = registerMap.i2cAddress;


  digitalWrite(statusLedPin, HIGH); //turn on the status LED to notify that we've setup everything properly
}

void loop(void)
{
  //Check to see if the I2C Address has been updated by software, set the appropriate address type flag
  if (oldAddress != registerMap.i2cAddress)
  {
    oldAddress = registerMap.i2cAddress;
    EEPROM.put(LOCATION_ADDRESS_TYPE, SOFTWARE_ADDRESS);
  }
  
  //update interruptPin output
  if (registerMap.eventStatus.eventAvailable && registerMap.interruptConfigure.interruptEnable)
  { //if the interrupt is triggered
    pinMode(interruptPin, OUTPUT); //make the interrupt pin a low-impedance connection to ground
    digitalWrite(interruptPin, LOW);
  }
  else
  { //go to high-impedance mode on the interrupt pin if the interrupt is not triggered
#if defined(__AVR_ATmega328P__)
    pinMode(interruptPin, INPUT_PULLUP);
#else
    pinMode(interruptPin, INPUT);
#endif
  }

  if (updateFlag == true)
  {
    //Record anything new to EEPROM (like new LED values)
    //It can take ~3.4ms to write a byte to EEPROM so we do that here instead of in an interrupt
    recordSystemSettings(&registerMap);

    updateFlag = false; //clear flag
  }
  
  sleep_mode();             //Stop everything and go to sleep. Wake up if I2C event occurs.
}

//Update slave I2C address to what's configured with registerMap.i2cAddress and/or the address jumpers.
void startI2C(memoryMap *map)
{
  uint8_t address;
  uint8_t addressType;
  EEPROM.get(LOCATION_ADDRESS_TYPE, addressType);

  if (addressType == 0xFF)
  {
    EEPROM.put(LOCATION_ADDRESS_TYPE, SOFTWARE_ADDRESS);
  }

  //PIR PCB has one jumper.
  uint8_t IOaddress = DEFAULT_I2C_ADDRESS;
  bitWrite(IOaddress, 0, digitalRead(addressPin));

  //If any of the address jumpers are set, we use jumpers
  if ((IOaddress != DEFAULT_I2C_ADDRESS) || (addressType == HARDWARE_ADDRESS))
  {
    address = IOaddress;
    EEPROM.put(LOCATION_ADDRESS_TYPE, HARDWARE_ADDRESS);
  }
  //If none of the address jumpers are set, we use registerMap (but check to make sure that the value is legal first)
  else
  {
    //if the value is legal, then set it
    if (map->i2cAddress > 0x07 && map->i2cAddress < 0x78)
      address = map->i2cAddress;

    //if the value is illegal, default to the default I2C address for our platform
    else
      address = DEFAULT_I2C_ADDRESS;
  }

  //save new address to the register map
  map->i2cAddress = address;

  //reconfigure Wire instance
  Wire.end();          //stop I2C on old address
  Wire.begin(address); //rejoin the I2C bus on new address

  //The connections to the interrupts are severed when a Wire.begin occurs, so here we reattach them
  Wire.onReceive(receiveEvent);
  Wire.onRequest(requestEvent);
}

//Reads the current system settings from EEPROM
//If anything looks weird, reset setting to default value
void readSystemSettings(memoryMap *map)
{
  //Read what I2C address we should use
  EEPROM.get(LOCATION_I2C_ADDRESS, map->i2cAddress);
  if (map->i2cAddress == 255)
  {
    map->i2cAddress = DEFAULT_I2C_ADDRESS; //By default, we listen for DEFAULT_I2C_ADDRESS
    EEPROM.put(LOCATION_I2C_ADDRESS, map->i2cAddress);
  }

  //Error check I2C address we read from EEPROM
  if (map->i2cAddress < 0x08 || map->i2cAddress > 0x77)
  {
    //User has set the address out of range
    //Go back to defaults
    map->i2cAddress = DEFAULT_I2C_ADDRESS;
    EEPROM.put(LOCATION_I2C_ADDRESS, map->i2cAddress);
  }

  //Read the interrupt bits
  EEPROM.get(LOCATION_INTERRUPTS, map->interruptConfigure.byteWrapped);
  if (map->interruptConfigure.byteWrapped == 0xFF)
  {
    map->interruptConfigure.byteWrapped = 0x03; //By default, enable the click and pressed interrupts
    EEPROM.put(LOCATION_INTERRUPTS, map->interruptConfigure.byteWrapped);
  }

  EEPROM.get(LOCATION_EVENT_DEBOUNCE_TIME, map->eventDebounceTime);
  if (map->eventDebounceTime == 0xFFFF)
  {
    map->eventDebounceTime = 10; //Default to 10ms
    EEPROM.put(LOCATION_EVENT_DEBOUNCE_TIME, map->eventDebounceTime);
  }
}

//If the current setting is different from that in EEPROM, update EEPROM
void recordSystemSettings(memoryMap *map)
{
  //I2C address is byte
  byte i2cAddr;

  //Error check the current I2C address
  if (map->i2cAddress >= 0x08 && map->i2cAddress <= 0x77)
  {
    //Address is valid

    //Read the value currently in EEPROM. If it's different from the memory map then record the memory map value to EEPROM.
    EEPROM.get(LOCATION_I2C_ADDRESS, i2cAddr);
    if (i2cAddr != map->i2cAddress)
    {
      EEPROM.put(LOCATION_I2C_ADDRESS, (byte)map->i2cAddress);
      EEPROM.put(LOCATION_ADDRESS_TYPE, SOFTWARE_ADDRESS);
      startI2C(map); //Determine the I2C address we should be using and begin listening on I2C bus
    }
  }
  else
  {
    EEPROM.get(LOCATION_I2C_ADDRESS, i2cAddr);
    map->i2cAddress == i2cAddr; //Return to original address
  }


  EEPROM.put(LOCATION_INTERRUPTS, map->interruptConfigure.byteWrapped);
  EEPROM.put(LOCATION_EVENT_DEBOUNCE_TIME, map->eventDebounceTime);
}

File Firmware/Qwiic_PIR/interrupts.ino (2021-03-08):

/******************************************************************************
  interrupts.ino
  Fischer Moseley @ SparkFun Electronics
  Original Creation Date: July 31, 2019

  This file contains the interrupt routines that are triggered upon an I2C write from
  master (receiveEvent), an I2C read (requestEvent), or a PIR state change
  (eventInterrupt). These ISRs modify the registerMap state variable, and sometimes
  set a flag (updateFlag) that updates things in the main loop.

  This code is beerware; if you see me (or any other SparkFun employee) at the
  local, and you've found our code helpful, please buy us a round!

  Distributed as-is; no warranty is given.
******************************************************************************/

//Turn on interrupts for the various pins
void setupInterrupts() {
  //Attach interrupt to switch
  attachPCINT(digitalPinToPCINT(pirPin), eventInterrupt, CHANGE);
}

//When Qwiic PIR receives data bytes from Master, this function is called as an interrupt
void receiveEvent(int numberOfBytesReceived) {
  registerNumber = Wire.read(); //Get the memory map offset from the user

  //Begin recording the following incoming bytes to the temp memory map
  //starting at the registerNumber (the first byte received)
  for (uint8_t x = 0 ; x < numberOfBytesReceived - 1 ; x++) {
    uint8_t temp = Wire.read(); //We might record it, we might throw it away

    if ( (x + registerNumber) < sizeof(memoryMap)) {
      //Clense the incoming byte against the read only protected bits
      //Store the result into the register map
      *(registerPointer + registerNumber + x) &= ~*(protectionPointer + registerNumber + x); //Clear this register if needed
      *(registerPointer + registerNumber + x) |= temp & *(protectionPointer + registerNumber + x); //Or in the user's request (clensed against protection bits)
    }
  }

  //Update the PIREvents and detect/remove queues.
  
  //If the user has requested to pop the oldest event off the stack then do so!
  if (registerMap.detectQueueStatus.popRequest) {
    //Update the register with the next-oldest timestamp
    detectEvents.pop();
    registerMap.detectQueueBack = detectEvents.back();

    //Update the status register with the state of the detectEvents buffer
    registerMap.detectQueueStatus.isFull = detectEvents.isFull();
    registerMap.detectQueueStatus.isEmpty = detectEvents.isEmpty();

    //Clear the popRequest bit so we know the popping is done
    registerMap.detectQueueStatus.popRequest = false;
  }
  
  //If the user has requested to pop the oldest event off the stack then do so!
  if (registerMap.removedQueueStatus.popRequest) {
    //Update the register with the next-oldest timestamp
    removedEvents.pop();
    registerMap.removedQueueBack = removedEvents.back();

    //Update the status register with the state of the removedEvents buffer
    registerMap.removedQueueStatus.isFull = removedEvents.isFull();
    registerMap.removedQueueStatus.isEmpty = removedEvents.isEmpty();

    //Clear the popRequest bit so we know the popping is done
    registerMap.removedQueueStatus.popRequest = false;
  }

  updateFlag = true; //Update things like LED brightnesses in the main loop
}

//Respond to GET commands
//When Qwiic PIR gets a request for data from the user, this function is called as an interrupt
//The interrupt will respond with bytes starting from the last byte the user sent to us
//While we are sending bytes we may have to do some calculations
void requestEvent() {
  registerMap.eventStatus.rawReading = digitalRead(pirPin);

  //Calculate time stamps before we start sending bytes via I2C
  registerMap.detectQueueBack = millis() - detectEvents.back();
  registerMap.detectQueueFront = millis() - detectEvents.front();
  
  registerMap.removedQueueBack = millis() - removedEvents.back();
  registerMap.removedQueueFront = millis() - removedEvents.front();

  //This will write the entire contents of the register map struct starting from
  //the register the user requested, and when it reaches the end the master
  //will read 0xFFs.

  Wire.write((registerPointer + registerNumber), sizeof(memoryMap) - registerNumber);
}

//Called any time the pin changes state
void eventInterrupt() {

  //Debounce
  if (millis() - lastEventTime < registerMap.eventDebounceTime)
    return;
  lastEventTime = millis();

  registerMap.eventStatus.eventAvailable = true;

  //Update the PIREvents queues and registerMap
  bool pinState = digitalRead(pirPin);
  switch (pinState)
  {
    case 0:
      registerMap.eventStatus.objectRemoved = true;
      registerMap.eventStatus.objectDetected = false;
      removedEvents.push(lastEventTime - registerMap.eventDebounceTime);
      registerMap.removedQueueStatus.isEmpty = removedEvents.isEmpty();
      registerMap.removedQueueStatus.isFull = removedEvents.isFull();
      break;
    case 1:
      registerMap.eventStatus.objectDetected = true;
      registerMap.eventStatus.objectRemoved = false;
      detectEvents.push(lastEventTime - registerMap.eventDebounceTime);
      registerMap.detectQueueStatus.isEmpty = detectEvents.isEmpty();
      registerMap.detectQueueStatus.isFull = detectEvents.isFull();
      break;
  }
}

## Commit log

2020-10-07 post checklist changes
    [Qwiic_PIR.brd, Qwiic_PIR.sch]
2020-10-12 adding fiducial to panel
    [Qwiic_PIR-Panel.GBL, Qwiic_PIR-Panel.GBO, Qwiic_PIR-Panel.GBP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]
2020-10-12 moving production folder
    [Qwiic_PIR-Panel.GBL, Qwiic_PIR-Panel.GBO, Qwiic_PIR-Panel.GBP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]
2020-10-12 changing panel to remove manually added fiducial
    [Qwiic_PIR-Panel.GBL, Qwiic_PIR-Panel.GBO, Qwiic_PIR-Panel.GBP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]
2020-10-21 adding panel for 1uA
    [Qwiic_PIR-Panel.GBL, Qwiic_PIR-Panel.GBO, Qwiic_PIR-Panel.GBP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]
2021-02-05 updating interrupts in firmware to single event triggered interrupt

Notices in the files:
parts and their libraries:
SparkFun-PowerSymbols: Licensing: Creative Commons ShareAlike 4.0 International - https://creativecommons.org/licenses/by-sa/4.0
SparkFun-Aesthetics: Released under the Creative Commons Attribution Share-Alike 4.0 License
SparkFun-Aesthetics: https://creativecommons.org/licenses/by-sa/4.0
